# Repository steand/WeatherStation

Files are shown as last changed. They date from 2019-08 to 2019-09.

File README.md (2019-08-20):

# Wetterstation

Version 0.1 *(under construction, not stabil)*

In diesem Projekt habe ich mir eine kleine Wetterstation gebaut.
Meine Motivation war, dass es eigentlich nichts erschwingliches gibt was in die offenen Smart-Home (bei mir openHAB2) integrierbar ist.

Leistungsmerkmale:
- Windgeschwindigkeit
- Windrichtung
- Regenmenge
- Regensensor
- Temperatur
- Luftdruck
- Luftfeuchtigkeit
- Helligkeit

Zur Steuerung meine Markise benötige ich Alarme für Regen und Windgeschwindigkeit.
Die Rolladen werden mit Hilfe der Helligkeitssensor gesteuert.

Für Windgeschwindigkeit, -richtung und Regenmenge dienen die Sensoren eine AOK5055.
Regensensor ist ein "China Modul".
Temperatur, Luftdruck und -feuchte basieren auf einem BME280,
Helligkeit auf dem BH1750.

Die Microcontroller Basis ist  ESP-WROOM-32u (u wegen der Antenne).

Als Stromversorung dient eine 18500/3000mAh Batterie die über ein Modul(TP4056) geladen wird.
Der Lader wird über ein MPPT-Modul (China) von einem 5W/12V Solarpenel versorgt.
Als SDK setze ich platformIO auf Basis von Atom ein.
Für Schaltpläne und Platinenlayout (Entwicklerplatine) nutze ich KiCad.

Weitere Details unter dem Verzeichnis ```
./doc
```.

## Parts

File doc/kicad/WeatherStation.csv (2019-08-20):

Source: | C:\Users\stefan\Develop\ESP\WeatherStation\Kicad\WeatherStation.sch
Date: | 08.08.2019 16:37:15
Tool: | Eeschema (5.1.2)-2
Component Count: | 53
Ref | Value | Footprint | Datasheet | Manufacturer | Vendor
BT1 | 18650 |  | ~
C1 | 10µ |  | ~
C2 | 1µF |  | ~
C3 | 10µ |  | ~
C4 | 100n |  | ~
C5 | 10µ |  | ~
C6 | 100n |  | ~
C7 | 47µ |  | ~
D1 | BAT42 |  | ~
D2 | BAT42 |  | ~
D3 | BAT42 |  | ~
D4 | BAT42 |  | ~
D5 | 1N4007 | Diode_THT:D_DO-41_SOD81_P10.16mm_Horizontal | http://www.vishay.com/docs/88503/1n4001.pdf
J1 | Conn_01x02 |  | ~
J2 | Conn_01x04 |  | ~
J3 | Screw_Terminal_01x02 |  | ~
J4 | Conn_01x04_Male |  | ~
J5 | Conn_01x02_Male |  | ~
J6 | Conn_01x04_Male |  | ~
J7 | Conn_01x02_Male |  | ~
J8 | Screw_Terminal_01x04 |  | ~
J9 | Screw_Terminal_01x02 |  | ~
J10 | Screw_Terminal_01x04 |  | ~
J11 | Screw_Terminal_01x02 |  | ~
J12 | Conn_01x02_Male |  | ~
J13 | Conn_01x02_Female |  | ~
J14 | Conn_01x03_Male |  | ~
J15 | Conn_01x03_Female |  | ~
J16 | Conn_01x02_Male |  | ~
J17 | Conn_01x02_Female |  | ~
J18 | Mess |  | ~
J19 | Prog |  | ~
J20 | Prog |  | ~
Q1 | IRLML2244 | Package_TO_SOT_SMD:SOT-23 | https://www.infineon.com/dgdl/irlml6402pbf.pdf?fileId=5546d462533600a401535668d5c2263c
Q2 | BC548 | Package_TO_SOT_THT:TO-92_Inline | http://www.fairchildsemi.com/ds/BC/BC547.pdf
Q3 | BC548 | Package_TO_SOT_THT:TO-92_Inline | http://www.fairchildsemi.com/ds/BC/BC547.pdf
R1 | 1M |  | ~
R2 | 120k |  | ~
R3 | 10K |  | ~
R4 | 470k |  | ~
R5 | 1M |  | ~
R6 | 10K |  | ~
R7 | R |  | ~
R8 | R |  | ~
SW1 | Reset |  | ~
SW2 | Mode |  | ~
U1 | BME280
U2 | BH1750
U3 | MPPT_StepDown
U4 | Rain_Sensor
U5 | LiIonCharger
U6 | ESP-WROOM-32 |  | https://www.espressif.com/sites/default/files/documentation/esp32-wroom-32_datasheet_en.pdf
U7 | MIC5501-3.0YM5 | Package_TO_SOT_SMD:SOT-23-5 | http://ww1.microchip.com/downloads/en/DeviceDoc/MIC550X.pdf

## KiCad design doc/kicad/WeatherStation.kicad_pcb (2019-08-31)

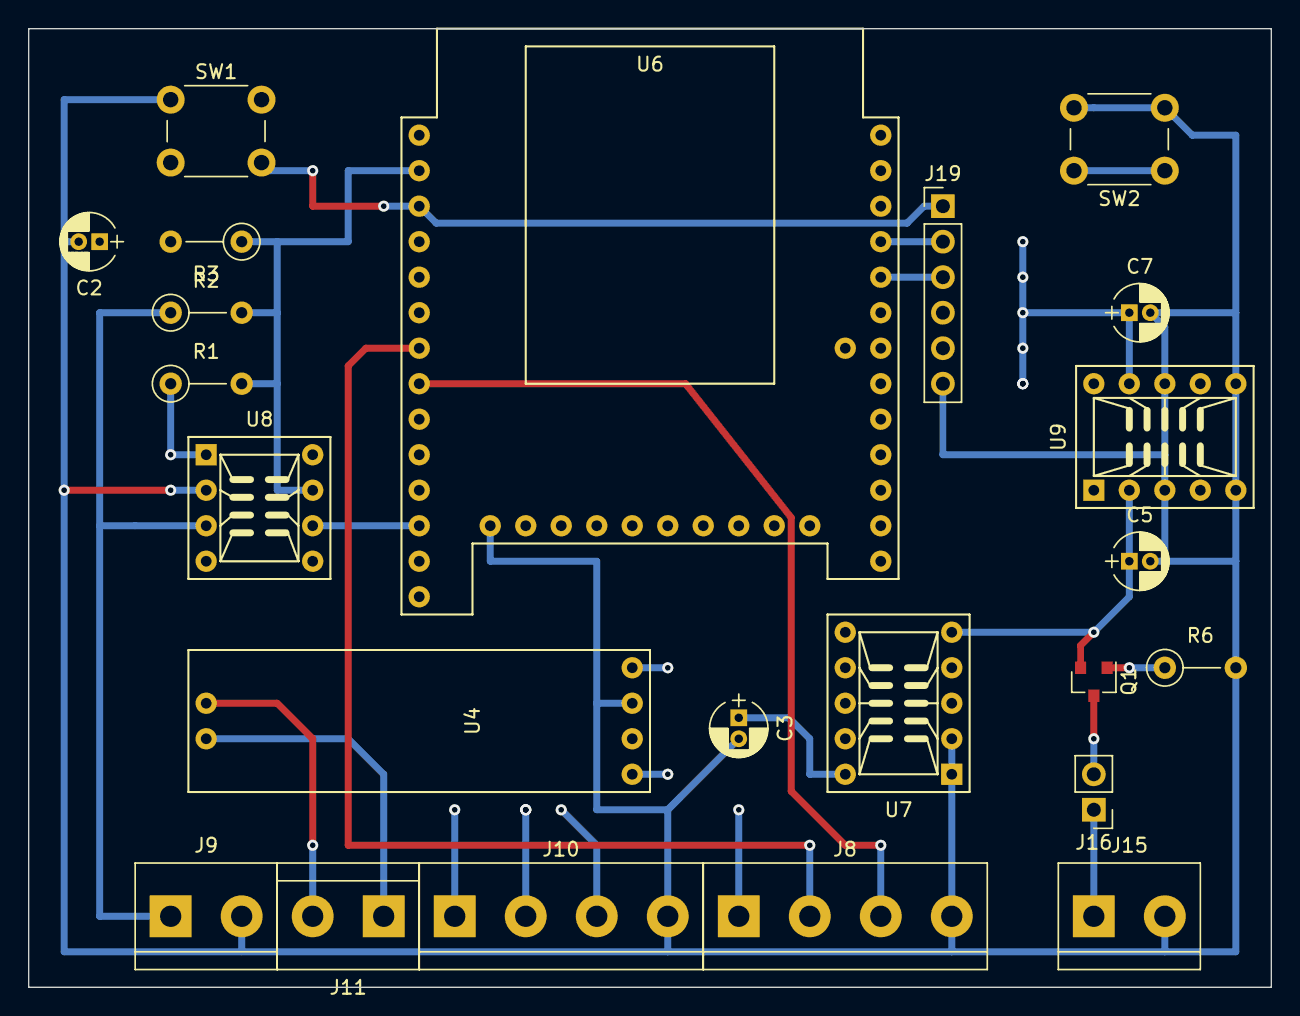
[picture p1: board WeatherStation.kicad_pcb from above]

Board: 4 copper layers, 88.9 x 68.6 mm, 23 parts (0 on the bottom side), 23 nets.

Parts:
C2: 1µF; CP_Radial_D4.0mm_P1.50mm
C3, C7: 10µ; CP_Radial_D4.0mm_P1.50mm
C5: 1µ; CP_Radial_D4.0mm_P1.50mm
J8, J10: Screw_Terminal_01x04; TerminalBlock_bornier-4_P5.08mm
J9, J11, J15: Screw_Terminal_01x02; TerminalBlock_bornier-2_P5.08mm
J16: Conn_01x02_Male; Pin_Header_Straight_1x02_Pitch2.54mm
J19: Prog; Socket_Strip_Straight_1x06_Pitch2.54mm
Q1: IRLML2244; SOT-23
R1, R2: 100k; R_Axial_DIN0207_L6.3mm_D2.5mm_P5.08mm_Vertical
R3, R6: 10K; R_Axial_DIN0207_L6.3mm_D2.5mm_P5.08mm_Vertical
SW1: Reset; SW_PUSH_6mm
SW2: Mode; SW_PUSH_6mm
U4: Rain_Sensor
U6: ESP-WROOM-32; ESP32_Dev_Board
U7: Mod_Spannungsteiler; Mod_SOT23_TO_10DIL
U8: Mod_Dual_Schmitt_Triger; Mod_TSOP6_TO_8DIL
U9: Mod_Regulator_3.0V; Mod_SOT23_TO_10DIL

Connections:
+3V0: C7.1, J8.1, R1.2, R2.2, R3.1, U6.2, U7.4, U8.7, U9.9
+BATT: C5.1, Q1.2, U7.5, U9.2
/ADC1: C3.1, U6.4, U7.10
/ADC2: U4.4, U6.5
/DATA: J10.2, U6.10
/INT: U6.11, U8.8
/INT\EXT0: U6.12, U8.6
/PROG: J19.5, SW2.1, U6.25
/Power1: U4.1, U6.6
/Power2: J10.1, U6.9
/RST: C2.1, J19.1, R3.2, SW1.2, U6.3
/RxD: J19.3, U6.34
/SDA: J8.3, U6.8
/SLC: J8.2, U6.7
/TxD: J19.2, U6.35
/WindTic: J10.3, R1.1, U8.1
GND: C2.2, C3.2, C5.2, C7.2, J8.4, J9.2, J10.4, J15.2, J19.6, R6.2, SW1.1, SW2.2, U4.3, U6.15, U7.1, U7.2, U8.2, U9.3
unnamed: J9.1, R2.1, U8.3
unnamed: J11.1, U4.6
unnamed: J11.2, U4.5
unnamed: J15.1, J16.1
unnamed: J16.2, Q1.3
unnamed: Q1.1, R6.1

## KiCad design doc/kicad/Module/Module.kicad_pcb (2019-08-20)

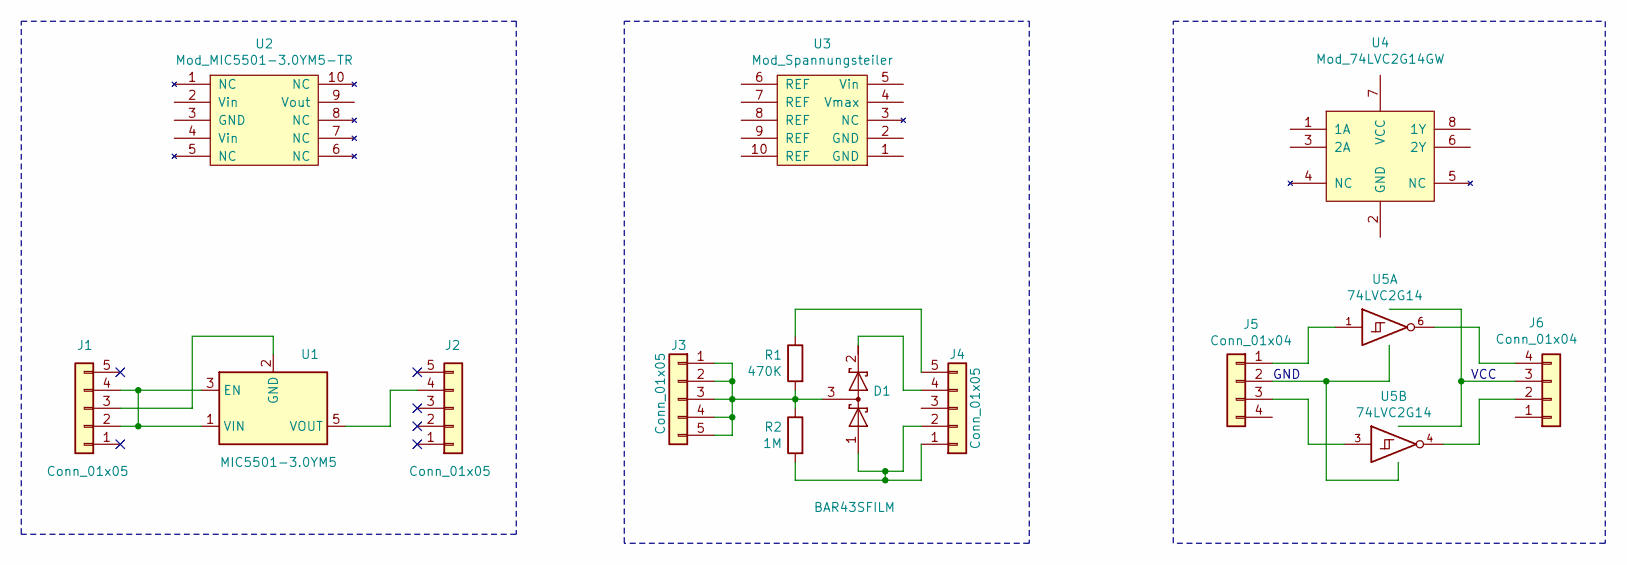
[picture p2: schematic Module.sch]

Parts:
D1: BAR43SFILM; SOT-23
J1, J2: Conn_01x05; Pin_Header_Straight_1x05_Pitch2.54mm
J3, J4: Conn_01x05; Socket_Strip_Straight_1x05_Pitch2.54mm
J5, J6: Conn_01x04; Socket_Strip_Straight_1x04_Pitch2.54mm
R1: 470K; R_0805
R2: 1M; R_0805
U1: MIC5501-3.0YM5; SOT-23-5
U2: Mod_MIC5501-3.0YM5-TR; Mod_SOT23_TO_10DIL
U3: Mod_Spannungsteiler; Mod_SOT23_TO_10DIL
U4: Mod_74LVC2G14GW; Mod_TSOP6_TO_8DIL
U5: 74LVC2G14; SOT-363_SC-70-6

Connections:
GND: J5.2, U5.2 (GND)
unnamed: D1.1 (A), J4.1, J4.2, R2.2
unnamed: D1.2 (K), J4.4
unnamed: D1.3 (AK), J3.1, J3.2, J3.3, J3.4, J3.5, R1.2, R2.1
unnamed: J1.2, J1.4, U1.1 (VIN), U1.3 (EN)
unnamed: J1.3, U1.2 (GND)
unnamed: J2.4, U1.5 (VOUT)
unnamed: J4.5, R1.1
unnamed: J5.1, U5.1
unnamed: J5.3, U5.3
unnamed: J6.2, U5.4
unnamed: J6.4, U5.6
VCC: J6.3, U5.5 (VCC)

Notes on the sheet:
VCC
GND

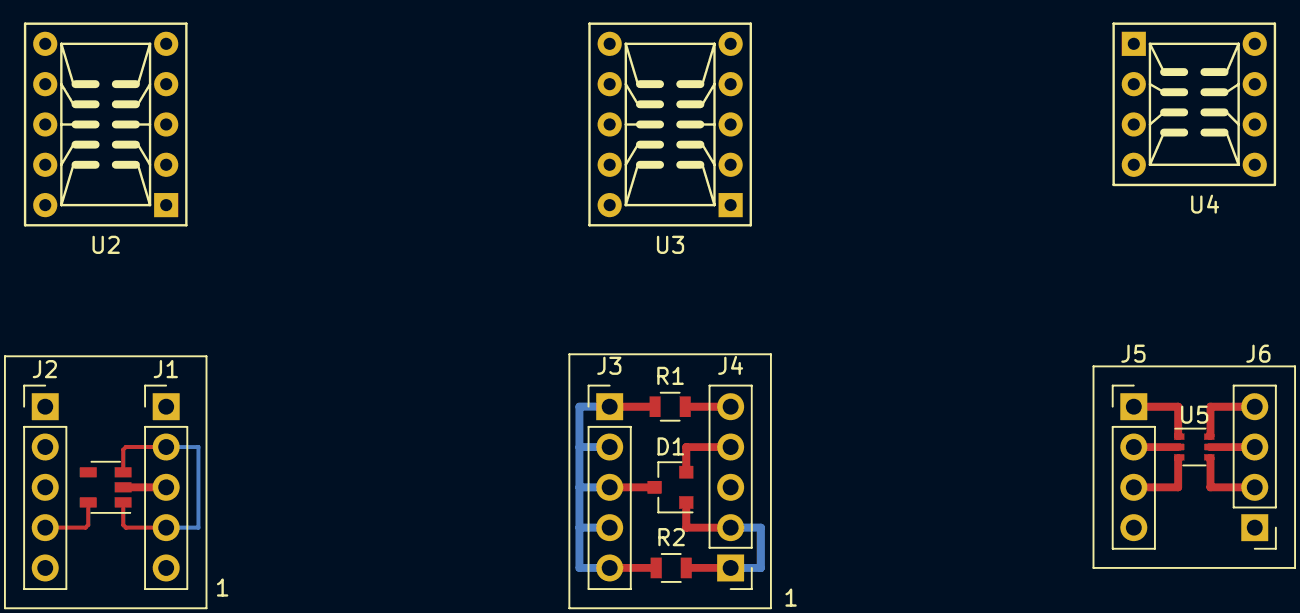
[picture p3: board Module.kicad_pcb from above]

Board: 2 copper layers, 14 parts (0 on the bottom side), 13 nets.

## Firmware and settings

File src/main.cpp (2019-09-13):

/*
main.cpp - Main of WeatherStation
Copyright (C) 2019  by Stefan Andres

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
You should have received a copy of the GNU General Public License
along with this program.  If not, see <https://www.gnu.org/licenses/>.
*/

#include <Arduino.h>
#include "Debug.h"
#include <WiFi.h>
#include "WeatherMQTT.h"
#include "RainSensor.h"
#include "esp_wifi.h"
#include "esp_bt.h"
#include "esp_bt_main.h"
#include <Wire.h>
#include <BH1750.h>
#include <Adafruit_Sensor.h>
#include <Adafruit_BME280.h>
#include "AOK5055.h"
#include "ADCtoV.h"
#include "WatchDog.h"

//include secure networkSetup.h, if exist
#if __has_include("networkSetup.h")
#include "networkSetup.h"
#endif

#ifndef NETWORKSETUP_H_
//Wifi
#define WIFI_SSID     "<your-SSID>"
#define WIFI_PASSWORD "<your-Password>"

// MQTT
#define MQTT_SERVER    "<your MQTT Server>"
#define MQTT_CLIENT_ID "WeatherClientID"
#define MQTT_USER      "<your MQTT user>"
#define MQTT_PASSWORD  "<your MQTT Password>"

#endif

#define WIFI_CONNECT_TIMEOUT 1500   //ms wait to connect

// defaults
#define DEFAULT_SEND_CYCLE 180           // send every 3 Minutes
#define DEFAULT_RAIN_PER_TICK 0.47       // one tic =  0.47 mm
#define DEFAULT_WIND_SPEED_PER_TICK 2.4  //  one tic/second = 2.4 km/h
#define DEFAULT_RAIN_ALARM_VALUE 3850    // max 4096 = no rain (ADC) must calibrated
#define DEFAULT_WIND_ALARM_VALUE 15.0    // Alarm when Speed more then 15km/h
#define DEFAULT_ALTITUDE 505             // Altidue over NN for relative pressure
#define DEFAULT_RAINSENSOR_ALARM_RESET_TIME 600  //ms
#define DEFAULT_WIND_ALARM_RESET_TIME 600  //ms
// RainSensor
#define RAINSENSOR_PIN 39
#define RAINSENSOR_POWER 21        // Switch power on for meassurement
// I2C, BME280, BH1750
#define WEATHER_I2C_SLC_PIN 19
#define WEATHER_I2C_SLA_PIN 18
#define WEATHER_BH1750_ADDR 0x23
#define BRIGHTNESS_FACTOR 1.44
// AOK5055
#define AOK_RAIN_PIN 16
#define AOK_RAIN_GPIO_PIN GPIO_NUM_16
#define AOK_POWER_PIN 33
#define AOK_WIND_SPEED_PIN 26
#define AOK_WIND_DIRECTION_PIN 25
//battery
#define BATTERY_PIN ADC1_GPIO36_CHANNEL
#define BATTERY_DIVIDER 1.4102F  // ToDo: Kalliebrierung
// solar panel
#define SOLAR_ADC_PIN ADC1_GPIO34_CHANNEL
#define SOLAR_POWER_PIN 32
#define SOLAR_DIVIDER 10.9589F
#define SOLAR_MIN_MPPT_VOLTAGE 16.0F   // If less SolarPanel will short disconnect


WeatherMQTT  mqtt;
RainSensor   rainSensor;
BH1750 lightMeter(WEATHER_BH1750_ADDR);
Adafruit_BME280 bme;
AOK5055 aok;
ADCtoV adc(ADC_UNIT_1);

boolean wifiConnect(){
  DEBUG_println("Connect Wifi");
  WiFi.mode(WIFI_STA);
  delay(10);
  WiFi.begin(WIFI_SSID, WIFI_PASSWORD);
  int i = 0;
  while ( WiFi.status() != WL_CONNECTED ) {
    DEBUG_print("." );
    delay(100);
    if (i++ > WIFI_CONNECT_TIMEOUT/100) {
      DEBUG_println("!");
      DEBUG_println("Wifi connection died!!!!");
      return false;
    }
  }
  delay(10);
  DEBUG_printf("WiFi Status: %d -> On\n", (WiFi.status())); // spend time for system CPU
  DEBUG_println("");
  DEBUG_printf("Connection takes : %dms\n",i*100);
  DEBUG_print("Mac address: "); DEBUG_println(WiFi.macAddress());
  DEBUG_print("IP address: ");  DEBUG_println(WiFi.localIP());
  return true;
}


void wifiDisconnect(){
  WiFi.disconnect();
  delay(10);
  DEBUG_printf("WiFi Status: %d -> Disconnect\n", (WiFi.status())); // spend time for system CPU
  delay(10);  // spend time for system CPU
  WiFi.mode(WIFI_OFF);
  delay(10);
  DEBUG_printf("WiFi Status: %d -> Off\n", (WiFi.status())); // spend time for system CPU
}

void goSleep(unsigned long sleepTime){
  unsigned long start = millis();
  esp_sleep_enable_timer_wakeup((sleepTime*1000));
  esp_light_sleep_start();
  unsigned long sleep = sleepTime-(millis()-start);
  switch (esp_sleep_get_wakeup_cause()) {
    case ESP_SLEEP_WAKEUP_TIMER: {
      DEBUG_printf("Wake up from timer. Time spent in sleep: %ldms\n", millis()-start);
      break;
    }
    case ESP_SLEEP_WAKEUP_GPIO: { // Rain wipp
      Serial.println("Wake up from GPIO (Rain)");
        // go sleep for rest of time (Realtime)
      if (sleep<sleepTime) delay(sleep);
      break;
    }
    default: {
      DEBUG_println("Wake up from other.");
      // go sleep for rest of time (Realtime)
      if (sleep<sleepTime) delay(sleep);
      break;
    }
  }
}

void readDefault() {
  if (!mqtt.restoreData()) {
    mqtt.cycle = DEFAULT_SEND_CYCLE;
    mqtt.windSpeedPerTic = DEFAULT_WIND_SPEED_PER_TICK;
    mqtt.rainPerTic = DEFAULT_RAIN_PER_TICK;
    mqtt.windAlarmValue = DEFAULT_WIND_ALARM_VALUE;
    mqtt.windAlarmResetTime = DEFAULT_WIND_ALARM_RESET_TIME;
    mqtt.rainAlarmValue = DEFAULT_RAIN_ALARM_VALUE;
    mqtt.rainAlarmResetTime = DEFAULT_RAINSENSOR_ALARM_RESET_TIME;
    mqtt.altitude = 505;
    mqtt.saveData();
  }
}

unsigned long oneMinute;
unsigned long cycleTime;
unsigned long cycleStartTime;
unsigned long startTime ;


void setup() {
  delay(1000); // Delay for load Elko's
  DEBUG_begin(115200);
  DEBUG_println("WeatherStation start in DEBUG Mode.");
  WiFi.mode(WIFI_STA);
  delay(10);  // spend time for system CPU
  wifiDisconnect();

  // bt not need
  esp_bt_controller_disable();
  esp_bluedroid_disable();

  readDefault();
  mqtt.begin(MQTT_SERVER,MQTT_CLIENT_ID,MQTT_USER,MQTT_PASSWORD);
  Wire.begin(WEATHER_I2C_SLA_PIN,WEATHER_I2C_SLC_PIN);
  //	i2cdetect();
  //BH1750
  	if (lightMeter.begin(BH1750::ONE_TIME_LOW_RES_MODE)) {
      DEBUG_println(("BH1750 Advanced begin"));
    }
    else {
      DEBUG_println("Error initialising BH1750");
    }
  // BME280
  	if (!bme.begin(0x76)) {
  		DEBUG_println("Could not find a valid BME280 sensor, check wiring!");
  	}
    else {
      DEBUG_println("Initialising BME280 OK");
    }
  rainSensor.begin(RAINSENSOR_PIN,RAINSENSOR_POWER,mqtt.rainAlarmValue);
  aok.begin(AOK_RAIN_PIN, AOK_POWER_PIN,AOK_WIND_SPEED_PIN, AOK_WIND_DIRECTION_PIN);
  adc.attachChannel(BATTERY_PIN);
  adc.attachChannel(SOLAR_ADC_PIN);
  pinMode(SOLAR_POWER_PIN, OUTPUT);
  digitalWrite(SOLAR_POWER_PIN, HIGH); // Switch on battery load
  gpio_wakeup_enable(AOK_RAIN_GPIO_PIN ,GPIO_INTR_HIGH_LEVEL);
  esp_sleep_enable_gpio_wakeup();
  mqtt.upTime = 0;
  oneMinute =  millis();
  cycleTime =  (unsigned long)mqtt.cycle * 1000;
  cycleStartTime = millis();
//  dog.start(20);
}


unsigned long rainAlarmTime,windAlarmTime;

boolean checkRainAlarm() {
  mqtt.rainSensor=rainSensor.read();
  if (mqtt.rainSensor <= mqtt.rainAlarmValue) {
    windAlarmTime = millis();
    if (!mqtt.rainAlarm) {
      mqtt.rainAlarm = true;
      return true;
    }
  } else {
    if (millis()-rainAlarmTime > mqtt.rainAlarmResetTime*1000) mqtt.rainAlarm = false;
  }
  return false;
}

boolean checkWindAlarm(){
  if (mqtt.windSpeedNow >= mqtt.windAlarmValue) {
      windAlarmTime = millis();
      if ( !mqtt.windAlarm) {
        mqtt.windAlarm = true;
        return true;
      }
  } else {
    if (millis()-windAlarmTime > mqtt.windAlarmResetTime*1000) mqtt.windAlarm = false;
  }
  return false;
}

void everyLoop() {
  aok.startWindSpeed();
  mqtt.rain = aok.getRain(mqtt.rainPerTic);
  mqtt.windSpeedNow = aok.stopWindSpeed(mqtt.windSpeedPerTic);
}

void cycleLoop() {
     // do work while wait for connection
     mqtt.battery = adc.read(BATTERY_PIN,BATTERY_DIVIDER);
     mqtt.solarVolt = adc.read(SOLAR_ADC_PIN,SOLAR_DIVIDER);
     byte windD = aok.getWindDirektion();
     if (windD < 16) mqtt.windDirection=windD;
     mqtt.rain = aok.getRain(mqtt.rainPerTic);
     mqtt.rain1h  = aok.getRain1h(mqtt.rainPerTic);
     mqtt.rain24h = aok.getRain24h(mqtt.rainPerTic);
     mqtt.windSpeed = aok.getWindSpeed(mqtt.windSpeedPerTic);
     mqtt.windSpeedMax = aok.getWindSpeedMax(mqtt.windSpeedPerTic);
     mqtt.brightness=lightMeter.readLightLevel()*BRIGHTNESS_FACTOR;
     DEBUG_printf("Brightness : %d \n",mqtt.brightness);
     mqtt.temperature = bme.readTemperature();
     mqtt.humidity = bme.readHumidity();
     float Th = mqtt.temperature + 273.15;
     mqtt.pressure = bme.readPressure()/100.0F * pow( Th / (Th + (0.0065 * mqtt.altitude)), -5.255);
}


byte loopCountMinute = 0;
int loopCountAll = 0;
boolean send = false;

void loop() {
  startTime = millis() ;
  // dog.feed();
  DEBUG_printf("everyLoop------------------------- %lu/%lu\n\n",millis()-oneMinute,millis() - cycleStartTime);
  aok.startWindSpeed();

  if (millis() - cycleStartTime >= cycleTime) {
    cycleStartTime = millis();
    DEBUG_printf("Cycle Hardbeat_________________________ %lu\n",millis() - cycleStartTime);
    cycleLoop();
    cycleTime =  (unsigned long)mqtt.cycle * 1000; //if Updated
    send=true;
  }

  if (checkRainAlarm()) send = true;  // every loop


 if (millis() - oneMinute >= 60000) {
   oneMinute = millis();
   DEBUG_println("One Minute Hardbeat____________________");
   mqtt.upTime++;
   aok.countOneMinute();
   // stop load battery for new calibration of MPPT
   if (mqtt.solarVolt < SOLAR_MIN_MPPT_VOLTAGE) digitalWrite(SOLAR_POWER_PIN, LOW);
 }

 mqtt.windSpeedNow = aok.stopWindSpeed(mqtt.windSpeedPerTic); //every loop


 if (checkWindAlarm() && !send) {
   send=true;
 }

 if (send) {
   if (wifiConnect()) mqtt.loop();
   mqtt.wifiRSSI = WiFi.RSSI();
   wifiDisconnect();
   send = false;
 }
digitalWrite(SOLAR_POWER_PIN, HIGH);  // Start load Battery
DEBUG_printf("Aktive Loop needs : %lu ms\n\n",millis()-startTime);
delay(100);
unsigned long neededTime=millis()-startTime;
if (neededTime<10000) goSleep(10000-neededTime);            // go sleep
DEBUG_printf("Loop needs : %lu ms\n",millis()-startTime);
}

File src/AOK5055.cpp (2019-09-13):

/*
AOK5055.cpp - This class implement the AOK5055 sensors.
Copyright (C) 2019  by Stefan Andres

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
You should have received a copy of the GNU General Public License
along with this program.  If not, see <https://www.gnu.org/licenses/>.
*/

#include <Arduino.h>
#include "AOK5055.h"
#include "Debug.h"


#define WIND_SPEED_MIN_MESSURE_TIME 1000

portMUX_TYPE mux = portMUX_INITIALIZER_UNLOCKED;


// Rain handling
volatile unsigned long rainTicks;
volatile unsigned long lastRainTick;
unsigned long  rainCycle;           // Rain in the cycle
unsigned long  rainMinute;           // Rain in the cycle
unsigned short rain1hArray[60];     // rain last 60 minutes
byte           rain1hIndex;
unsigned short rain24hArray[24];    // rain last day
byte           rain24hIndex;


void IRAM_ATTR isrRain() {
  if ((millis()-lastRainTick) > 50) { // kill all bounds les 50 ms
     portENTER_CRITICAL_ISR(&mux);
    rainTicks++;
     portEXIT_CRITICAL_ISR(&mux);
    lastRainTick = millis();
  }
}

// Wind handling

volatile byte windTicks;
volatile unsigned long lastWindTick;
unsigned long startWindTime;
volatile unsigned long  windSpeedArray[3];  // max Windspeed messure points
unsigned short windSpeedAverage[6];  // 1 Minute (6*10) times every Minute
unsigned short windSpeed10Average[10]; // 10 Minute  times every Minute
byte     windSpeedAverageIndex;
byte     windSpeed10AverageIndex;

unsigned long messMillis;

void IRAM_ATTR isrWind() {
   messMillis = millis();
  if ((messMillis-lastWindTick) > 5) { // kill all bounds les 5 ms
    portENTER_CRITICAL_ISR(&mux);
    if (windTicks < 3) windSpeedArray[windTicks] = messMillis;
      windTicks++;
      lastWindTick = messMillis;
    portEXIT_CRITICAL_ISR(&mux);
 }
}


AOK5055::AOK5055() {
}

void AOK5055::begin(uint8_t rainPin, uint8_t powerPin, uint8_t windSpeedPin, uint8_t windDirectionPin) {
  byte i;
  this->rainPin = rainPin;
  this->powerPin = powerPin;
  this->windSpeedPin = windSpeedPin;
  this->windDirectionPin = windDirectionPin;
  rainTicks = 0;
  rainCycle = 0;
  rainMinute = 0;
  for (i=0;i<60;i++) rain1hArray[i] = 0;     // tics last 60 minutes
  rain1hIndex=0;
  for (i=0;i<24;i++) rain24hArray[i]=0;    // tics last day
  rain24hIndex=0;
  for (i=0;i<6;i++) windSpeedAverage[i]=0xFFFF;
  for (i=0;i<10;i++) windSpeed10Average[i]=0xFFFF;
  windSpeedAverageIndex = 0;
  windSpeed10AverageIndex = 0;
  pinMode(rainPin,INPUT);
  pinMode(windSpeedPin,INPUT);
  pinMode(windDirectionPin,INPUT_PULLDOWN);
  pinMode(powerPin,OUTPUT);
  digitalWrite(this->powerPin, LOW); // Power off

   // Wind Trigger Pin Test only
  //  pinMode(4,OUTPUT);

  attachInterrupt(digitalPinToInterrupt(this->rainPin),isrRain, FALLING);

}


unsigned long windStartTime;

void AOK5055::startWindSpeed() {
  windTicks=0;
  lastRainTick = millis();
  startWindTime=millis();
  attachInterrupt(digitalPinToInterrupt(this->windSpeedPin),isrWind, FALLING);
}

float AOK5055::stopWindSpeed(float windSpeedPerTic) {
  float windSpeedNow = 0.0;
  portENTER_CRITICAL(&mux);
  byte wt = windTicks;
  portEXIT_CRITICAL(&mux);
  while (((millis() - startWindTime) <= WIND_SPEED_MIN_MESSURE_TIME) &&
           (wt < 3) ) {
             delay(10);
             portENTER_CRITICAL(&mux);
             wt = windTicks;
             portEXIT_CRITICAL(&mux);
           }
  detachInterrupt(digitalPinToInterrupt(this->windSpeedPin));
  DEBUG_printf("WindSpeed needs: %lu ms",millis() - startWindTime);
  // ToDo Speed berechnen
  windSpeedAverage[windSpeedAverageIndex] = 0xFFFF; // time = 1/speed
  if (windTicks == 1 ) windSpeedAverage[windSpeedAverageIndex] = WIND_SPEED_MIN_MESSURE_TIME;
  if (windTicks == 2 ) windSpeedAverage[windSpeedAverageIndex] = windSpeedArray[1]-windSpeedArray[0];
  if (windTicks == 3 ) windSpeedAverage[windSpeedAverageIndex] = (windSpeedArray[2]-windSpeedArray[0])/2;
  if (windSpeedAverage[windSpeedAverageIndex] == 0) windSpeedAverage[windSpeedAverageIndex] = 0xFFFF; //secure
  DEBUG_printf("stopWind Index: #%d -> #%d\n", windSpeedAverageIndex,windSpeedAverage[windSpeedAverageIndex]);
  if (++windSpeedAverageIndex >= 6 ) {
    windSpeedAverageIndex = 0;
    windSpeedNow = 0;
    for (byte i=0;i<6;i++ ) windSpeedNow = windSpeedNow + 1.0F/windSpeedAverage[i];
    windSpeed10Average[windSpeed10AverageIndex] = 1/(windSpeedNow / 6);
    if (++windSpeed10AverageIndex >= 10) windSpeed10AverageIndex = 0;
  }
  windSpeedNow = 0;
  for (byte i= 0;i<6;i++) windSpeedNow += 1000.0F/windSpeedAverage[i];
  DEBUG_printf("WindSpeed now is %.1f km/h\n",windSpeedPerTic * windSpeedNow/6);
  return windSpeedPerTic * (windSpeedNow/6);
}


// get Averange of 10 Minutes
// WMO definition
float AOK5055::getWindSpeed(float windSpeedPerTic) {
   float ws = 0;
   for (byte i= 0;i<10;i++) ws += 1000.0F/windSpeed10Average[i];
   ws = ws / 10.0;
   DEBUG_printf("%f 1/s - %.1f km/h\n",ws, windSpeedPerTic * ws);
   return windSpeedPerTic * ws;
}


float AOK5055::getWindSpeedMax(float windSpeedPerTic) {
  // of  last 10 Minute (60 meassures)
  unsigned short ws = 0xffff;
  for (byte i= 0;i<10;i++) {
    if ((windSpeed10Average[i] < ws )) ws = windSpeed10Average[i];
  }
  return windSpeedPerTic * (1000.0F/ (float)(ws));
}


byte AOK5055::getWindDirektion() {
  // one Serial steam 1 Start Bits 7 data
  // not realised by SoftwareSerial

  int i;
  unsigned long m;
  digitalWrite(this->powerPin, HIGH); // Power on
  // Search Start Bit
  m = pulseIn(windDirectionPin, HIGH,1000000);
  if  (m == 0) {
    DEBUG_println("getWindDirektion: TimeOut start bit not found");
    return 255;
  }
   DEBUG_println("Found: " + String(m));
//  Format: 010dddd
  uint8_t direction = 0;
  for (i=6;i>=0; i--) {
    m = pulseIn(windDirectionPin,HIGH,5000);
//    DEBUG_println(m);
    if ( m >750 ) bitSet(direction,i);
  }
  digitalWrite(this->powerPin, LOW); // Power off
  direction = (direction & 0x0f);
  DEBUG_println("getWindDirektion :" + String(direction) );
  return direction;

  }

// Rain calculation


void AOK5055::countOneMinute(){
  portENTER_CRITICAL(&mux);
  unsigned long rt=rainTicks;
  portEXIT_CRITICAL(&mux);
  unsigned short rain = rt-rainMinute;
  rain1hArray[rain1hIndex] = rain;
  rain24hArray[rain24hIndex] += rain;
  rainMinute = rt;
  DEBUG_printf("Last Minute rain #%d Ticks\n", rain1hArray[rain1hIndex] );
  if (++rain1hIndex >= 60) {
    rain1hIndex = 0;
    if (++rain24hIndex >= 24) rain24hIndex = 0;
    rain24hArray[rain24hIndex] = 0;
  }
}

float AOK5055::getRain(float rainPerTic) {  // Return Rain of last cycle
  portENTER_CRITICAL(&mux);
  unsigned long rt=rainTicks;
  portEXIT_CRITICAL(&mux);
  float rain = rainPerTic * (float)(rt-rainCycle);
  DEBUG_printf("getRain Tics Summe: #%lu, Delta: #%lu, Rain %fmm\n",rt,rt-rainCycle,rain);
  rainCycle = rt;
return rain;
}
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

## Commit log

2019-08-20 V0.1 (first Version)
    [Module.kicad_pcb, Module.sch, WeatherStation.csv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]
2019-08-31 Stable without Solar monitor
    [Anschlussbezeichnung.ods, Module.sch, WeatherStation.kicad_pcb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]
2019-09-13 Fixed WiFi freeze (ADC_2/Int Problems). Optimize Solar MPPT.
    [Module.sch, WeatherStation.sch]

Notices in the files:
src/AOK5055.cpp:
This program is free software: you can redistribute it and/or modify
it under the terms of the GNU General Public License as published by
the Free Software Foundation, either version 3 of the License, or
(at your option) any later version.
